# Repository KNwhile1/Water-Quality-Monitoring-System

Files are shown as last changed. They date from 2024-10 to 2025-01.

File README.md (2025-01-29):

# Project-PPS

# Water Quality Measurement Device for Lakes or Rivers with Geolocation, Connected to the Internet (Cloud)

## Context and Origin
Our company specializes in manufacturing devices to measure water quality in lakes and rivers. Traditionally, our teams travel by boat to take measurements on-site and collect water samples for laboratory analysis. Each measurement includes data on the date, time, temperature, geographical location, and water sample, all recorded on paper. One employee had the innovative idea of creating a device that would automatically take measurements and record data without the need for paper notes or water samples. This device would allow real-time water quality measurements and instantly send the data to our databases to be visualized on a Google Maps map, offering up-to-date accessibility for everyone.

In order to bring this vision to life and continue our commitment to environmental health, we have decided to develop and commercialize this product, which will replace our current methods.

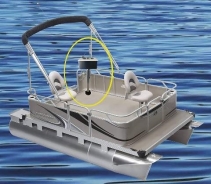
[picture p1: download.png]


## General Need
The required device is a water quality measurement system capable of collecting and transmitting data on the concentration of certain gases (such as oxygen) and water temperature. It must include geolocation, battery level, and send the data to a cloud platform via the LoRaWAN network. The data should be displayed on a Google Maps map.

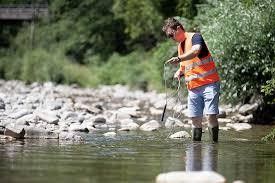
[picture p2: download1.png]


## Objectives
- Design a device capable of measuring water quality
- Transmit the collected data to a cloud platform accessible by employees
- Display water quality data on a Google Maps map in real-time
- Key Functions

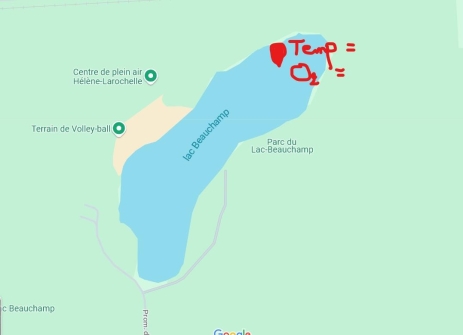
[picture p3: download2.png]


## The device can
- Measure oxygen (O2) concentration in the water
- Measure water temperature
- Provide geolocation data (latitude and longitude), as well as the date and time of the measurement
- Indicate voltage and battery level
- Send the collected data via the LoRaWAN network to a cloud platform (ThingsBoard)
- Update data every 5 minutes
- Display the collected data on an integrated Google Maps map on the ThingsBoard platform

## Required Components (images)
- Maduino Zero LoRaWAN
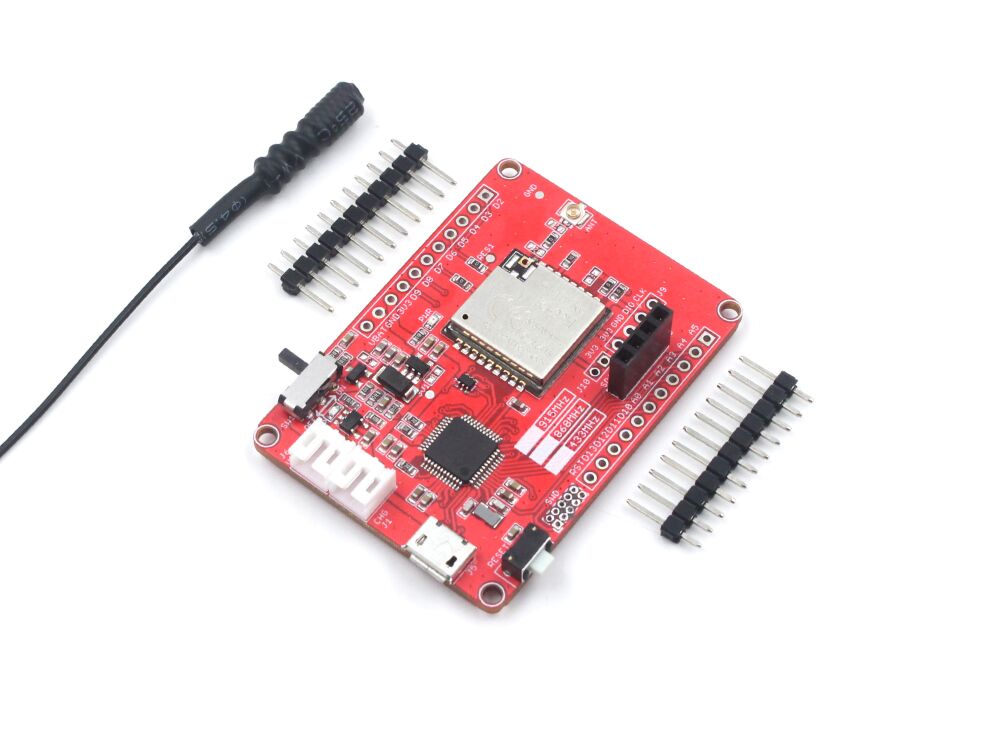
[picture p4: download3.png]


- Waterproof 1-WIRE temperature sensor (5V)
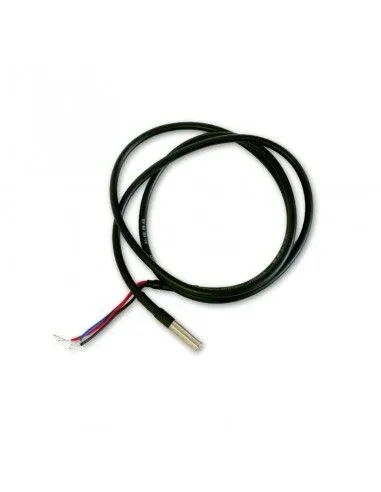
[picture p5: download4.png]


- Waterproof oxygen concentration sensor (5V)
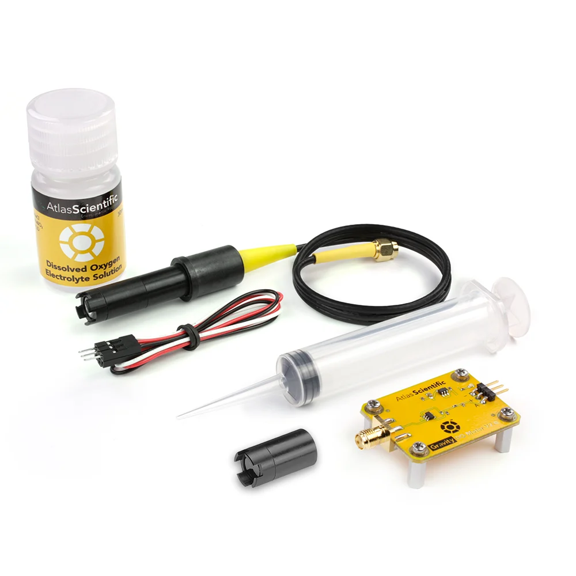
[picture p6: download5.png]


- 1K Ohm 1206 resistor
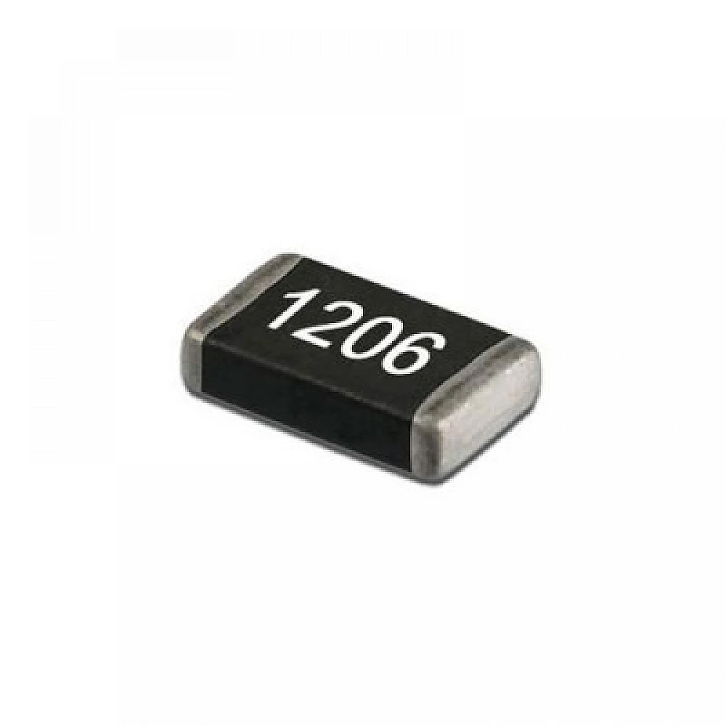
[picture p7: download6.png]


- 2 AA 1.5V batteries
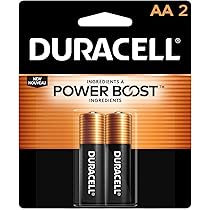
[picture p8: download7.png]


- Battery holder for 2 AA batteries
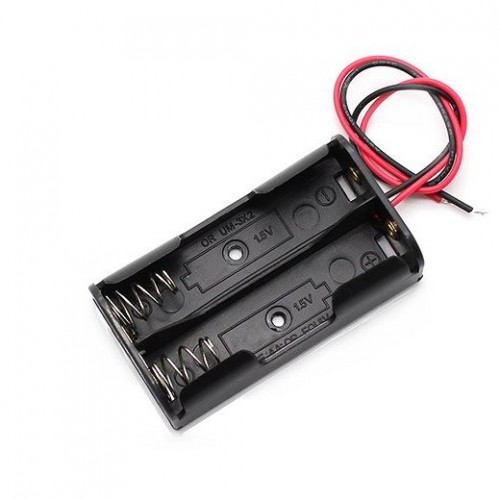
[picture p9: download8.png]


- On/Off switch to control power
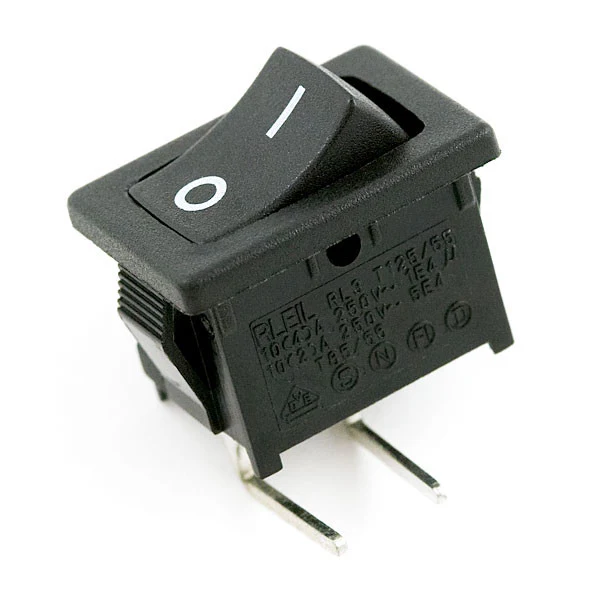
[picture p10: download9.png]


- 3.3V to 5V boost converter
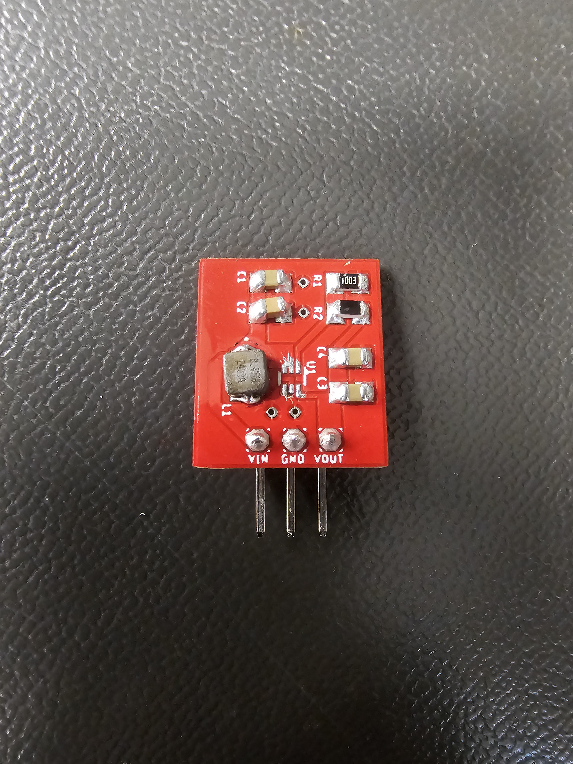
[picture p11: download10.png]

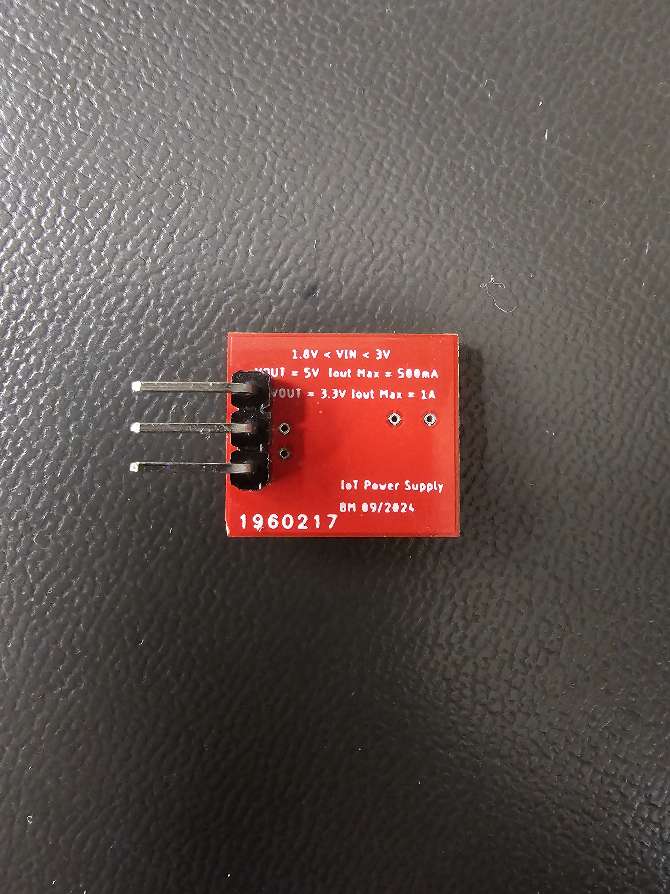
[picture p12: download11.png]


*See the **Project Purchase Links** category for purchase links*

## Conclusion
This project aims to revolutionize how we measure and track the water quality of lakes and rivers. With this device, we will be able to provide precise, instant, and accessible data to our entire team while ensuring improved environmental monitoring.

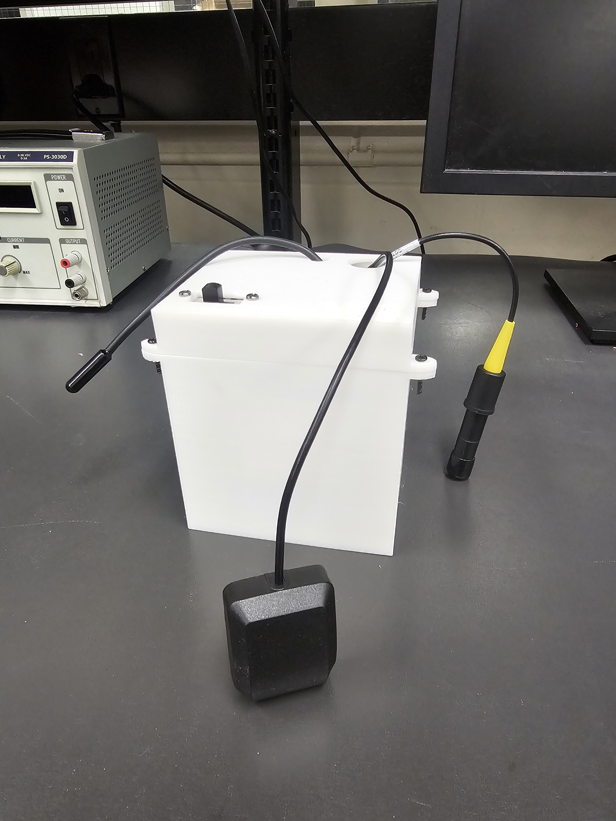
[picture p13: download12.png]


*Representation of the project assembly*

# Functional File Versions for this Project
- /Codes/CodeV1.3 ---> **CodeV1.3.ino**
- /3D_Prints/Boiter3DV1.1 ---> **PPS_Boitier.stl** and **PPS_CouvercleBoitier.stl**
- /Schematics/CircuitV1.3 ---> **PPS_schematic.sch**
- /Schematics/MatrixV1.3 ---> **PPS_schematic.brd**

# Problems Encountered
See /Problem_List ---> Liste_problemes_PPS.xlsx

# Project Purchase Links
See /Component_List ---> Liste_composants_PPS.xlsx

# Additional Information Links
- [CayenneLPP](https://github.com/myDevicesIoT/CayenneLPP)
- [Arduino LoRaWAN Device Library](https://github.com/TheThingsNetwork/arduino-device-lib)
- [ASR650X AT Command Introduction](https://www.hoperf.com/data/upload/back/20190605/ASR650X%20AT%20Command%20Introduction-20190605.pdf)
- [Maduino Zero LoRaWAN](https://github.com/Makerfabs/Maduino-Zero-Lorawan/tree/Ra07)
- [Github chirpstack docker](https://github.com/chirpstack/chirpstack-docker)
- [ChirpStack Documentation](https://www.chirpstack.io/docs/)
- [ThingsBoard Documentation](https://thingsboard.io/)

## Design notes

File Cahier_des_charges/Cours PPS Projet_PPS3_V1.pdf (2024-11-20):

Cours PPS_Projet PPS3_V1 | Copyleft B. Manai

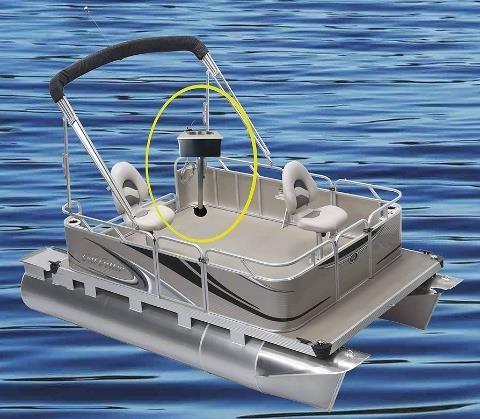
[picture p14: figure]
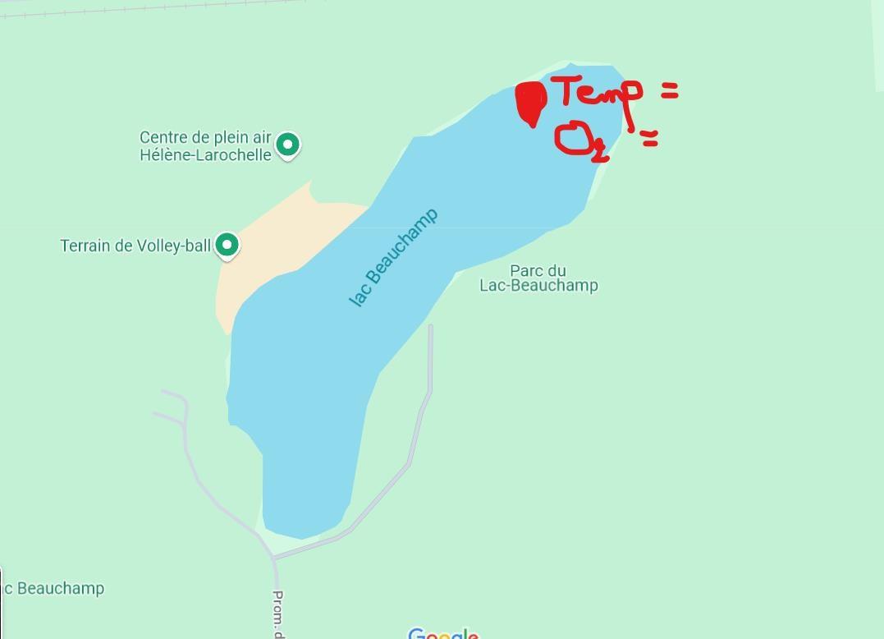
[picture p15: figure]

2024-10-03

## Cours Préparation au Projet et au Stage (PPS)

## Projet : Dispositif de mesure de la qualité de l'eau d'un lac ou d'une rivière avec géolocalisation connecté à internet (Cloud)

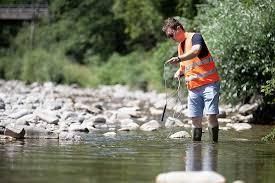
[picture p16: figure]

A. Contexte et origine
Notre compagnie fabrique des dispositifs de mesure de la qualité de l'eau des lacs et des rivières. Habituellement nos équipes se déplace sur un bateau/barque pour faire des mesures sur place et recueillir des échantillons afin de les analyser au laboratoire. Chaque mesure correspond à une date, une heure, une température, une position géographique et un échantillon d'eau. L'ensemble est consigné dans un support papier et l'échantillon dans un contenant pour l'analyse au laboratoire. Une idée novatrice nous a été proposé par un de nos employés qui a imaginé un dispositif qui permettrait de faire les mesures et relèvement en une seule fois sans devoir prendre des notes sur papiers ni d'échantillons. Ainsi la qualité de l’eau est mesurée au moment de la sortie et les données sont envoyées instantanément à nos bases de données et reportées directement sur une carte de type Google Maps de sorte que toutes les personnes puissent connaitre la qualité de l’eau à chaque instant. Comme nous avons le souci de la santé environnementale nous avons donc décidé de réaliser ce produit qui sera vendu et remplacera les produits existants
Nous avons pensé donc à la réalisation d’un dispositif de 1ème génération permettant l’envoi des mesures de la concentration de O2 et de la température de l'eau via le réseau LoRaWAN directement sur une plateforme infonuagique (Cloud) et les afficher sur Google Maps.
B. Besoin général

Le besoin est un dispositif de mesure de la qualité de l’eau. La mesure de la qualité de l’eau se faitsur la base de mesures de concentration dansl’eau de certains gaz comme l'oxygène O2. Les fonctions principales sont la mesure des concentrations, la géolocalisation, la tension de la batterie et l’envoi des données via LoRaWAN sur une plateforme connectée à internet et l’affichage des données sur une carte Google Maps.

C. Objectifs
L’objectif ici est de concevoir et réaliser un dispositif qui serait capable de mesurer la qualité de l’eau et l’afficher sur une carte de type Google Maps à l’endroit et à l’heure où les données ont été requises ainsi que l’envoie de ces données sur une plateforme cloud accessible aux employés.
D. Fonctions principales
- La solution doit pouvoir mesurer la concentration d’oxygène (O2) dans l’eau.
- La solution doit pouvoir mesurer la concentration d’azote () dans l’eau.
- La solution doit pouvoir mesurer la température de l’eau.
- La solution doit pouvoir fournir les données géographiques de l’endroit où l’échantillon a été recueilli ainsi que la date et l’heure.
- La solution doit pouvoir être alimentée par du 5V.
- La solution doit pouvoir renseigner sur l’état de la batterie.

- La solution doit pouvoir envoyer les données (concentration des gaz, Température de l’eau, tension de la batterie, niveau de la batterie) via LoRaWan sur une la platform Cloud ThingsBoard.
- La solution doit pouvoir mettre à jour les données toutes les 5 minutes.
- Les données de solution doivent pouvoir être accessibles par les bases de données de l'entreprise.
- La solution doit pouvoir afficher les données sur les concentrations de gaz, sur la température de l’eau et le niveau de batterie sur une carte de type Google Maps.
- La solution doit pouvoir afficher la carte Google Maps sur la plateforme ThingsBoard.
E. Contraintes
a. Alimentation

2 piles AA de 1.5V chacune

1 support pour 2 piles AA

1 interrupteur Marche/Arrêt

b. Capteurs

Temperature, O2

c. MCU / Module WiFi
Maduino LoRaWAN d. Support de la partie électronique

Carte de montage électronique et produit fini sur PCB simple ou double face. Les MCUs ne doivent pas être soudés sur la carte. Prévoir des supports pour cette fin.

e. Boitier 3D

Une simple boite parallélépipédique suffit largement. Doit comporter un accès au port USB de programmation du MCU. Les interrupteurs doivent être accessible depuis l’extérieur du boitier. Un accès des capteurs à l’extérieur du boitier doit être assuré. Pour des raisons de sécurité aucune colle ne sera permise pour coller le PCB au boitier. Prévoir 4 trous aux 4 coins du PCB pour une fixation au boitier avec des vis M2.

f. Cloud

Doit afficher sur une carte Google Maps les valeurs en temps réel de la température, les concentrations de gaz, la tension de la batterie et signaler un niveau de batterie faible, lorsque la tension de la batterie devient inférieure à 2x1V.

Doit utiliser la plateforme ThingsBoard. Doit afficher la concentration en O2 et la température de l'eau sur une période d’une journée avec mise à jour toutesles 5 minutes. Affichage de la valeur actuelle. Doit afficher la tension de la batterie et signaler un niveau de batterie faible lorsque la tension de la batterie devient inférieure à 2x1V. Doit reporter sur une carte Google Maps les dernières valeurs mesurées de la concentration en O2, la température de l'eau et du niveau de la batterie.

g. Plateforme de développement
Fusion 360
h. Plateforme de documentation
La gestion du projet doit être entièrement réalisé sur GitHub
F. Acteurs
Les | différents | acteurs | liés | à | ce | projet | sont | les | suivants | :
Concepteurs/conceptrices | :
- | Camille | Courtemanche, | en | charge | du | PCB
- | Andyl | Omontola | Ouabi, | en | charge | de | l’alimentation
- | Kirstan | Niamba, | en | charge | du | cloud
- | Esther | Priscilla | Zoukou, | en | charge | du | boiter
Autres | | | | | | | | | | :
-M. | Bilal | Manaï, | client
-M. Bilal Manaï, superviseur du projet et enseignant au département TGÉ du Cégep de l’Outaouais
-M. Maxime Gillespie, technicien du département TGÉ du Cégep de l’Outaouai
-M. Alexis Maisonneuve, technicien du département TGÉ du Cégep de l’Outaouais

G. Livrables
- | | Cartes | | | électroniques
- | Bureau | d’affichage | des | données | (Thingsboard)
- | | Produit | | | assemblé
- | | | Produit | | installé
- | | Accès | | aux | données
H. Échéancier
14 | | | novembre | | 2024
I. Budget
Maximum de 100 dollars canadien

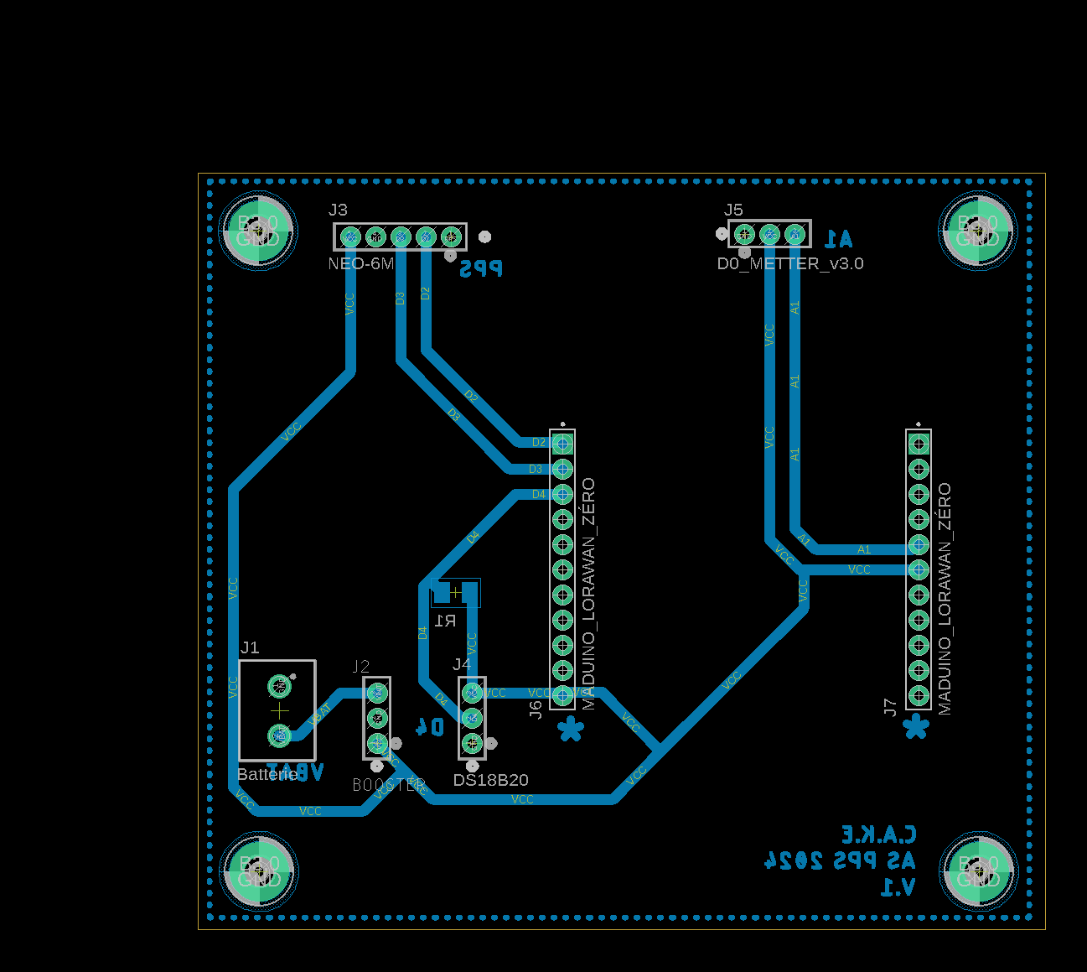
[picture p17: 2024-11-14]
Schématiques/MatricielV1.3/PPS_schematic.png

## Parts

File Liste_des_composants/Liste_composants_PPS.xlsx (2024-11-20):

Liste des pieces
Élève : Camille Courtemanche |  |  | Tuteur: Bilal Manaï
Projet : PPS |  |  |  |  |  |  | Prix/composant (hors taxes) |  | Total | Page web (URL | Fiche technique | Image | Remarque du client | Remarques du technicien
Quantité | numéro de pièce (SKU) | Fabricant | Fournisseur | Fourni par | Disponible (magasin) | Description | USD | CAD | $710.68
2 | PPTC031LFBN-RC | Sullins Connector Solutions | Digikey | Département (magasins) | oui | 3 Positions Embase Connecteur 0,100 po (2,54mm) Trou traversant Étain (Connecteur Femelle) | $0.65 | $0.91 | $1.82 | https://www.digikey.ca/fr/products/detail/sullins-connector-solutions/PPTC031LFBN-RC/810143 | https://mm.digikey.com/Volume0/opasdata/d220001/medias/docus/937/Female_Headers.100_DS.pdf |  |  | Contient 3 Pins (femelle)
2 | M20-7821146 | Harwin Inc. | Digikey | Département (magasins) | oui | 12 Positions Embase Connecteur 0,100 po (2,54mm) Trou traversant Étain | $2.56 | $3.58 | $7.17 | https://www.digikey.ca/fr/products/detail/harwin-inc/M20-7821146/3919446 | https://cdn.harwin.com/pdfs/M20-782.pdf |  |  | Contient 11 Pins (femelle)
1 | RC1206FR-074K7L | YAGEO | Digikey | Département (magasins) | oui | 4.7 kOhms ±1% 0,25W, 1/4W Pavé résistif 1206 (3216 métrique) Résistant à l’humidité Couche épaisse | $0.16 | $0.22 | $0.22 | https://www.digikey.ca/fr/products/detail/yageo/RC1206FR-074K7L/728887 | https://www.yageo.com/upload/media/product/products/datasheet/rchip/PYu-RC_Group_51_RoHS_L_12.pdf
1 | 08055C102KAT2A | Würth Elektronik | Digikey | Département (magasins) | oui | 2 Borniers - Fil à carte Horizontal avec carte 0,197po (5,00mm) Trou traversant | $0.58 | $0.81 | $0.81 | https://www.digikey.ca/fr/products/detail/w%C3%BCrth-elektronik/691137710002/6644051 | https://www.we-online.com/components/products/datasheet/691137710002.pdf
1 | PPTC051LFBN-RC | Sullins Connector Solutions | Digikey | Département (magasins) | oui | 5 Positions Embase Connecteur 0,100 po (2,54mm) Trou traversant Étain | $0.84 | $1.18 | $1.18 | https://www.digikey.ca/fr/products/detail/sullins-connector-solutions/PPTC051LFBN-RC/807239 | 5 Positions Embase Connecteur 0,100 po (2,54mm) Trou traversant Étain
1 | RG191 | Ezurio LLC | Digikey | Département (magasins) | oui | GATEWAY WIFI LORA ETHERNET US | $265.00 | $371.00 | $371.00 | https://www.digikey.ca/en/products/detail/ezurio-llc/RG191/7356131?gad_source=1 | https://connectivity-staging.s3.us-east-2.amazonaws.com/2020-03/CS-PB-RG1xx-GATEWAY_v1_5.pdf
1 | RB-Mkf-36 | OPHMALORA | RobotShop | Département (magasins) | oui | LPWAN ASSET TRACKER KIT AMAZON | A/N | $33.52 | $33.52 | https://ca.robotshop.com/products/maduino-zero-lorawan-915mhz?gad_source=1 | https://wiki.seeedstudio.com/Wio-Tracker_Introduction/
1 | MOD-120 Neo-6M UBLOX GPS Module | ABRA | ABRA | Département (magasins) | oui | GPS module with antenna, adapter, battery. Extra : clock pulse output pin | A/N | $32.62 | $32.62 | https://abra-electronics.com/wireless/gps/modules/mod-120-neo-6m-ublox-gps-module.html | https://content.u-blox.com/sites/default/files/products/documents/NEO-6_DataSheet_%28GPS.G6-HW-09005%29.pdf
1 | SEN-11050 | SparkFun Electronics | Digikey | Département (magasins) | oui | TEMP SENSOR WTRPRF DS18B20 11050 | $11.25 | $15.75 | $15.75 | https://www.digikey.ca/en/products/detail/sparkfun-electronics/SEN-11050/5721423?gad_source=1 | https://mm.digikey.com/Volume0/opasdata/d220001/medias/docus/1818/SEN-11050_Web.pdf
1 | RB-Atl-54 | Kit-105DX | RobotShop | Département (magasins) | oui |  | A/N | $246.41 | $246.41 | https://ca.robotshop.com/products/gravity-analog-dissolved-oxygen-kit?gad_source=1 | https://cdn.robotshop.com/media/a/atl/rb-atl-73/pdf/gravity-analog-dissolved-oxygen-meter-datasheet.pdf
1 | 61300311121 | Würth Elektronik | Digikey | Département (magasins) | oui | CONN HEADER VERT 3POS 2.54MM | $0.13 | $0.18 | $0.18 | https://www.digikey.ca/en/products/detail/w%C3%BCrth-elektronik/61300311121/4846825?productid=4846825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 | https://www.we-online.com/components/products/datasheet/61300311121.pdf

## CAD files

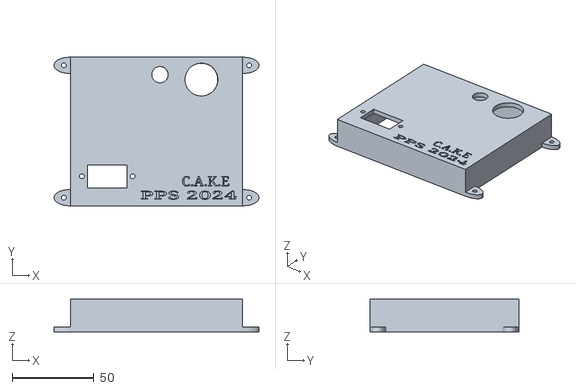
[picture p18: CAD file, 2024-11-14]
Impressions3D/Boiter3DV1/PPS_CouvercleBoitier.stl
125.0 x 90.7 x 20.0

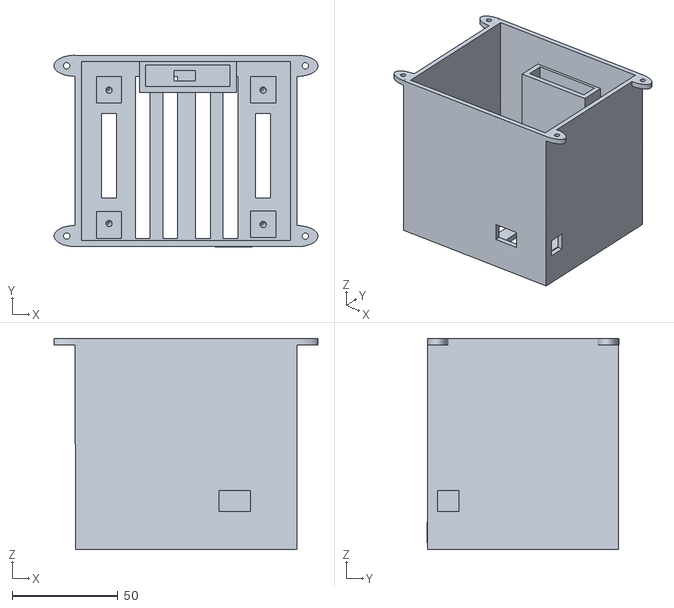
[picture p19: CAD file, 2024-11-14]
Impressions3D/Boiter3DV1/PPS_Boitier.stl
125.1 x 90.8 x 100.0

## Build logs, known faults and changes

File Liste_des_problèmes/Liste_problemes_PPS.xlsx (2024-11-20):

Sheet: Feuille 1
Dans cette colomne préciser le nom de votre équipe | Dans cette colomne préciser le titre de votre projet PPSx | Dans cette colomne compléter les Prénoms, Noms de l'équipe |  |  | Dans cette colomne décrire au moins 3 problèmes rencontrés pour chaque composante (matérielle, logicielle, réseau et cloud) | Dans cette colomne décrire les solutions envisagées en vis à vis de chaque problème | Dans cette colomne préciser quelle solution a été choisie | Dans cette colomne préciser pour quelles raisons la solution a été choisie
Projet | Équipe | Membres de l'équipe | Composante | Problème | Description du problème | Solutions | Choix | Argumentation
 |  |  | Matérielle (au sens électronique : PCB, plaque à essai, ...) | 1 |  | 1:
 |  |  |  |  |  | 2:
 |  |  |  |  |  | 3 :
 |  |  |  | 2 |  | 1:
 |  |  |  |  |  | 2:
 |  |  |  | 3 |  | 3:
 |  |  |  | 4 |  | 1:
 |  |  |  |  |  | 2:
 |  |  |  |  |  | 3:
 |  |  | Logicielle (embarqué) | 1 |  | 1:
 |  |  |  |  |  | 2:
 |  |  |  |  |  | 3 :
 |  |  |  | 2 |  | 1:
 |  |  |  |  |  | 2:
 |  |  |  | 3 |  | 1:
 |  |  |  |  |  | 2 :
 |  |  |  |  |  | 3 :
 |  |  | Réseau (WiFi / LoRaWAN) | 1 |  | 1 :
 |  |  |  |  |  | 2 :
 |  |  |  |  |  | 3 :
 |  |  |  | 2 |  | 1 :
 |  |  |  |  |  | 2 :
 |  |  |  | 3 |  | 1 :
 |  |  |  |  |  | 2 :
 |  |  |  |  |  | 3:
 |  |  | Cloud (ThingsBoard) | 1 |  | 1:
 |  |  |  |  |  | 2 :
 |  |  |  |  |  | 3 :
 |  |  |  | 2 |  | 1 :
 |  |  |  |  |  | 2 :
 |  |  |  | 3 |  | 1 :
 |  |  |  |  |  | 2 :
 |  |  |  |  |  | 3 :
 |  |  | Boitier (3D) | 1 |  | 1:
 |  |  |  |  |  | 2 :
 |  |  |  |  |  | 3 :
 |  |  |  | 2 |  | 1 :
 |  |  |  |  |  | 2 :
 |  |  |  | 3 |  | 1 :
 |  |  |  |  |  | 2 :
 |  |  |  |  |  | 3:

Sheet: BlueScreen
Dans cette colomne préciser le titre de votre projet PPSx | Dans cette colomne préciser le nom de votre équipe | Dans cette colomne compléter les Prénoms, Noms de l'équipe |  |  | Dans cette colomne décrire au moins 3 problèmes rencontrés pour chaque composante (matérielle, logicielle, réseau et cloud) | Dans cette colomne décrire les solutions envisagées en vis à vis de chaque problème | Dans cette colomne préciser quelle solution a été choisie | Dans cette colomne préciser pour quelles raisons la solution a été choisie
Projet | Équipe | Membres de l'équipe | Composante | Problème | Description du problème | Solutions | Choix | Argumentation
Projet PPS2 : | Équipe BlueScreen | David Landry, Jérémie Cadieux, Tristan Comtois et Damien Tweedy | Matérielle (au sens électronique : PCB, plaque à essai, ...) | 1 | La première version de notre PCB a été mal conçue et n'avait pas pris en considération que pour les composantes traversantes c'est sur la couche bottom que nous devions souder. Cela a eu comme incidence qu'une fois assemblé, notre Maduino était à l'envers. | 1: Essayer de souder les collecteurs en surface | Choix 2 | Problème 1 : Nous avons choisit de repenser et refaire la matricielle car il y avait beaucoup de problème de conception majeur avec notre première version imprimer de notre PCB. De plus nous en avons profiter pour réduire considérablement la dimension du PCB pour permettre le montage sur un casque de vélo plus réaliste. Problème 2 : Nous avons choisit de faire un seul BOOST de 5V pour alimenté le Maduino avec son entré VBAT car celui-ci à un option intégré de fournir de 3V3 que nous pouvons utilisé pour alimenté notre capteur GPS. Cette options est plus compacte et consomme moins d'énergie électriquement que les choix 1 et 2. Problème 3 : Nous avons choisit de vérifier les soudures et de faire des tests électriques. Nous avons trouvé un problème important. VIN et le GROUND étaient connectés ensemble à l'intérieur du bornier male. Le plastique avait fondu et connecté les deux signaux électriquement. Nous avons dessoudé et resoudé un autre connecteur. Le VOUT est maintenant 2.4V, on suspecte qu'il y a un problème avec la composante tps61023dlr.
 |  |  |  |  |  | 2:Repenser et refaire la matricielle en prenant en considération l'orientation et la couche de soudure.
 |  |  |  |  |  | 3 :
 |  |  |  | 2 | Choix des sources d’alimentation 5V et 3V3, Nous avons changé d’idée à plusieurs reprises lors de la considération des sources d’alimentation 5V et 3V3. | 1:Faire un boost de 5V et utilisé un régulateur de tension 3.3V. Cette solution c’est avéré être mauvaise car elle utilisait des composantes qui consommait trop de courant par rapport à d’autre options possibles. | Choix 3
 |  |  |  |  |  | 2:Utilisé 2 boosts (3,3V et 5V) pour alimenter nos composantes. Nous avons vite rejeté cette option lorsque nous avons consulté en profondeur la datasheet et les schématiques du Maduino Zero pour réaliser qu’en utilisant une alimentation par batterie, le Maduino devait être alimenté par du 5V et à la possibilité intégrée de fournir de 3,3V.
 |  |  |  |  |  | 3: Faire un seul boost de 5V pour alimenter le Maduino via le connecteur VBAT et utilisé l’interrupteur SW1 pour choisir l’alimentation USB ou via la Batterie. On utilise le 3,3V fournis par le Maduino pour alimenter le module GPS et le boost de 5V pour alimenter le capteur de gaz.
 |  |  |  | 3 | Problème avec le Boost 5V, une fois le circuit soudé, il ne fournissait pas 5V en sortie. Nous avons mis 3V en entré avec 30mA et mesuré VOUT et VOUT. VIN = 2.98V et VOUT = 0 | 1: Vérifier les soudures et refaire celle qui sembre être flottante | Choix 2 et 3
 |  |  |  |  |  | 2: Test de continuité en mode résistance avec notre multimètre
 |  |  |  |  |  | 3: Refaire le circuit avec de nouvelles composantes
 |  |  |  | 1 | Problème avec l’utilisation du GPS avec communication UART (RX et TX). | 1: Utiliser les bibliothèques tel que SoftwareSerial ou AltSoftSerial pour réassigné les pins RX et TX | Choix 2
 |  |  | Logicielle (embarqué) |  |  | 2: Utiliser les pin D2 et D3 en l'assignation sercom2 . |  | Problème 1 : Nous avons choisit d'utiliser les pins D2 et D3 pour faire la communications UART RX et TX car nous avons vu plusieurs autre projet en ligne qui utilisait c'est 2 pins avec d'autre capteurs avec le même Maduino. Les librairies du choix 1 n'est pas compatible avec notre microcontroleurs. Le choix 3 requière l'ajoût d'une autre composante qui prend de la place, consomme de l'électricité et nous n'étions pas certain que sa serait fonctionnelle. Nous avons donc décidé de ne pas choisir cette solution. Problème 2 : Nous avons essayé d'utilisé des lingetttes alcoolisé et d'autre librairie, mais nous n'avons pas été capable de capté des données pertinante avec le capteur de gaz.
 |  |  |  |  |  | 3 : Utiliser un convertisseur CP2104 USB à Seriel
 |  |  |  | 2 | Problème avec l'utilisation du capteur de gaz, nous étions limité avec les tests de fonctionalités. Nous recevions des valeurs PPM qui n'était pas possible | 1 : Utilisé le capteur de gaz pour détecté l'alcool et utilisé des serviettes nettoyante alcolisé. | Choix 1 et 3
 |  |  |  |  |  | 2 : Essayer d'autre librairies avec notre capteur de gaz
 |  |  |  |  |  | 3 : Essayer un autre capteur de gaz pour vérifier si le notre avait des défectuosités
 |  |  |  | 3 |  | 1 :
 |  |  |  |  |  | 2: | Choix
 |  |  |  |  |  | 3 :
 |  |  |  | 1 | Difficulté à se familiariser avec LoRaWan et Chirpstack | 1 : Lire des blogs et regarder des videos sur le sujet | Choix 1 et 2
 |  |  | Réseau (WiFi / LoRaWAN) |  |  | 2 : Écouter la démonstration de maxime |  | Problème 1 : Travailler avec ChirpStack et LoRaWAN était accablant au début, car c'était un domaine nouveau pour nous. Nous avons donc commencé par lire et nous informer sur le sujet avant de nous lancer dans cette partie du projet. Problème 2 : Après avoir connecté le Maduino Zero à ChirpStack via LoRaWAN, nous avons réussi à recevoir les données, mais nous n'avons pas réussi à les envoyer vers ThingsBoard.
 |  |  |  |  |  | 3 :
 |  |  |  | 2 | Problème lorsque des informations sont envoyer via Chirpstack | 1 : Relire le tutoriel de Maxime sur LoRaWAn | Choix 1 et 2
 |  |  |  |  |  | 2 : Créer une nouvelle application, avec une nouvelle clé
 |  |  |  | 3 |  | 1 :
 |  |  |  |  |  | 2 : | Choix
 |  |  |  |  |  | 3:
 |  |  |  | 1 | Difficulté à se familiarriser avec ThingsBoard et le Dashboard ( widgets, google map) | 1 : Regarder des tutoriels | Choix 1
 |  |  | Cloud (ThingsBoard) |  |  | 2 : Essayer les differents widgets dans des examples |  | Problème 1 : De manière similaire à ChirpStack et LoRaWAN, nous avons dû nous familiariser avec ThingsBoard et les différents widgets du tableau de bord. Nous avons regardé des tutoriels et, finalement, nous avons réussi à créer un tableau de bord adéquat pour notre projet. Problème 2 : Lors des tests de la capacité de ThingsBoard à recevoir des données, nous pouvions envoyer des valeurs fixes via le terminal Windows, mais nous n'avons pas réussi à recevoir les valeurs de notre capteur de gaz ou du GPS via le Maduino Zero.
 |  |  |  |  |  | 3 :
 |  |  |  | 2 | Difficulté recevoir les informations de Chirpstack sur ThingsBoard | 1 : Lire la documentation que maxime a créer sur tge.info | Choix 1
 |  |  |  |  |  | 2 : Changer la configuration de Chirpstack et ThingsBoard
 |  |  |  | 3 |  | 1 :
 |  |  |  |  |  | 2 : | Choix
 |  |  |  |  |  | 3 :
 |  |  |  | 1 | Problème avec les dimensions de la première version du boîtier, les murs étaient trop épaisses et celui-ci était trop gros pour porter sur un casque. | 1: Refaire le boîtier au complet pour que celui-ci respecte les normes d'épaisseur, de compactibilité et de grandeur. | Choix 1 et 2
 |  |  | Boitier (3D) |  |  | 2 : Raptisser les parois du boîtier pour qu'il puisse être plus compact et qu'il puisse s'installer sur un casque de vélo. |  | Problème 1 : Le problème de la première version du boîtier était que les parois étaient trop épaisses, ce qui empêchait son installation adéquate sur un casque de vélo. En refaisant le boîtier, nous avons pu réduire l'épaisseur des parois pour qu'il soit plus compact et qu'il puisse s'installer correctement sur le casque de vélo. Problème 2 : Les dimensions de la deuxième version du boîtier sont encore inexactes. Les parois sont trop minces pour permettre l'insertion des vis nécessaires à la fermeture du boîtier, et la fente n'autorise pas un accès facile au Maduino. En refaisant le boîtier avec des parois un peu plus épaisses et en agrandissant l'ouverture pour faciliter l'accès au Maduino, nous obtiendrons un boîtier conforme à nos exigences. Problème 3 : Les dimensions des trous pour le capteur d'air et l'interrupteur sont trop petites, ce qui empêche leur insertion précise dans le boîtier. En limant les trous, nous avons pu corriger les légères erreurs d'impression en les agrandissant.
 |  |  |  |  |  | 3 : Ajuster les trous et les parois à la lime pour qu'il soit à la bonne épaisseur et grandeur.
 |  |  |  | 2 | Deuxième version : dimension des troues d'attachement pour le couvercle et la fente à l'avant est trop petite pour permettre l'accès du Maduino de l'extérieur | 1 : Refaire le boîtier pour aggrendir les parois pour pouvoir insérer des vis et avoir un accès plus facile du Maduino de l'extérieur.
 |  |  |  |  |  | 2 : Ajuster les trous à la lime pour y insérer les vis et le composant. | Choix 1
 |  |  |  |  |  | 3 : Percer les trous pour y insérer les vis.
 |  |  |  | 3 | Dimension des troues pour le capteur et la switch n'étaient pas parfaitement la bonne dimmension. | 1 : Refaire le boîtier pour aggrendir les trous pour pouvoir insérer le capteur et la switch sans avoir besoin de limer les extrémiter.
 |  |  |  |  |  | 2 : Ajuster les trous à la lime pour y insérer les composants. | Choix 2
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

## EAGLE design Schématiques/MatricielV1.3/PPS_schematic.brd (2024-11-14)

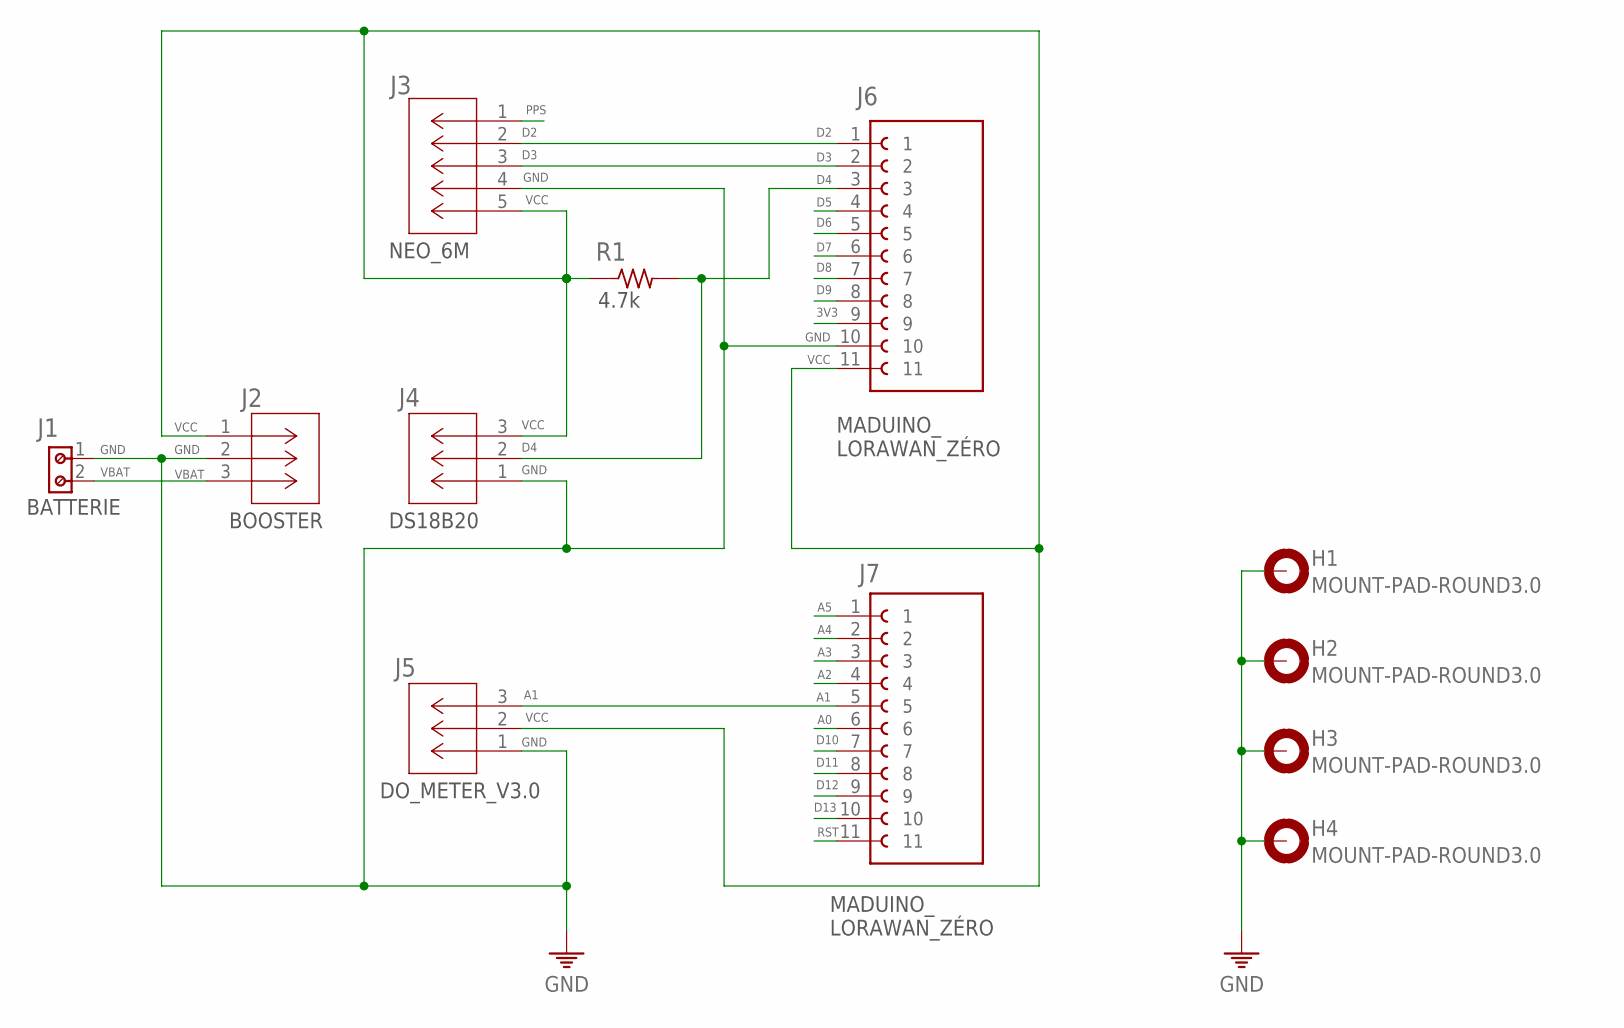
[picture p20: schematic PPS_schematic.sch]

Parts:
H1, H2, H3, H4: MOUNT-PAD-ROUND3.0; 3,0-PAD
J1: Batterie; 691137710002
J2: BOOSTER; CON3_1X3_TU_HTS_SAI
J3: NEO-6M; CONN5_1LFBN-RC_SUL
J4: DS18B20; CONN_PPTC031_SUL
J5: D0_METTER_v3.0; CONN_PPTC031_SUL
J6, J7: MADUINO_LORAWAN_ZÉRO; HARWIN_M20-7821146
R1: 4.7k; M1206

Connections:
3V3: J6.9
A1: J5.3, J7.5
A2: J7.4
A3: J7.3
A4: J7.2
A5: J7.1
D2: J3.2, J6.1
D3: J3.3, J6.2
D4: J4.2, J6.3, R1.2
D5: J6.4
D6: J6.5
D7: J6.6
D8: J6.7
D9: J6.8
D10: J7.7
D11: J7.8
D12: J7.9
D13: J7.10
GND: H1.B3,0, H2.B3,0, H3.B3,0, H4.B3,0, J1.1, J2.2, J3.4, J4.1, J5.1, J6.10
PPS: J3.1
RST: J7.11
VBAT: J1.2, J2.3

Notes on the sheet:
BOOSTER
DS18B20
DO_METER_V3.0
NEO_6M
BATTERIE
MADUINO_ LORAWAN_ZÉRO

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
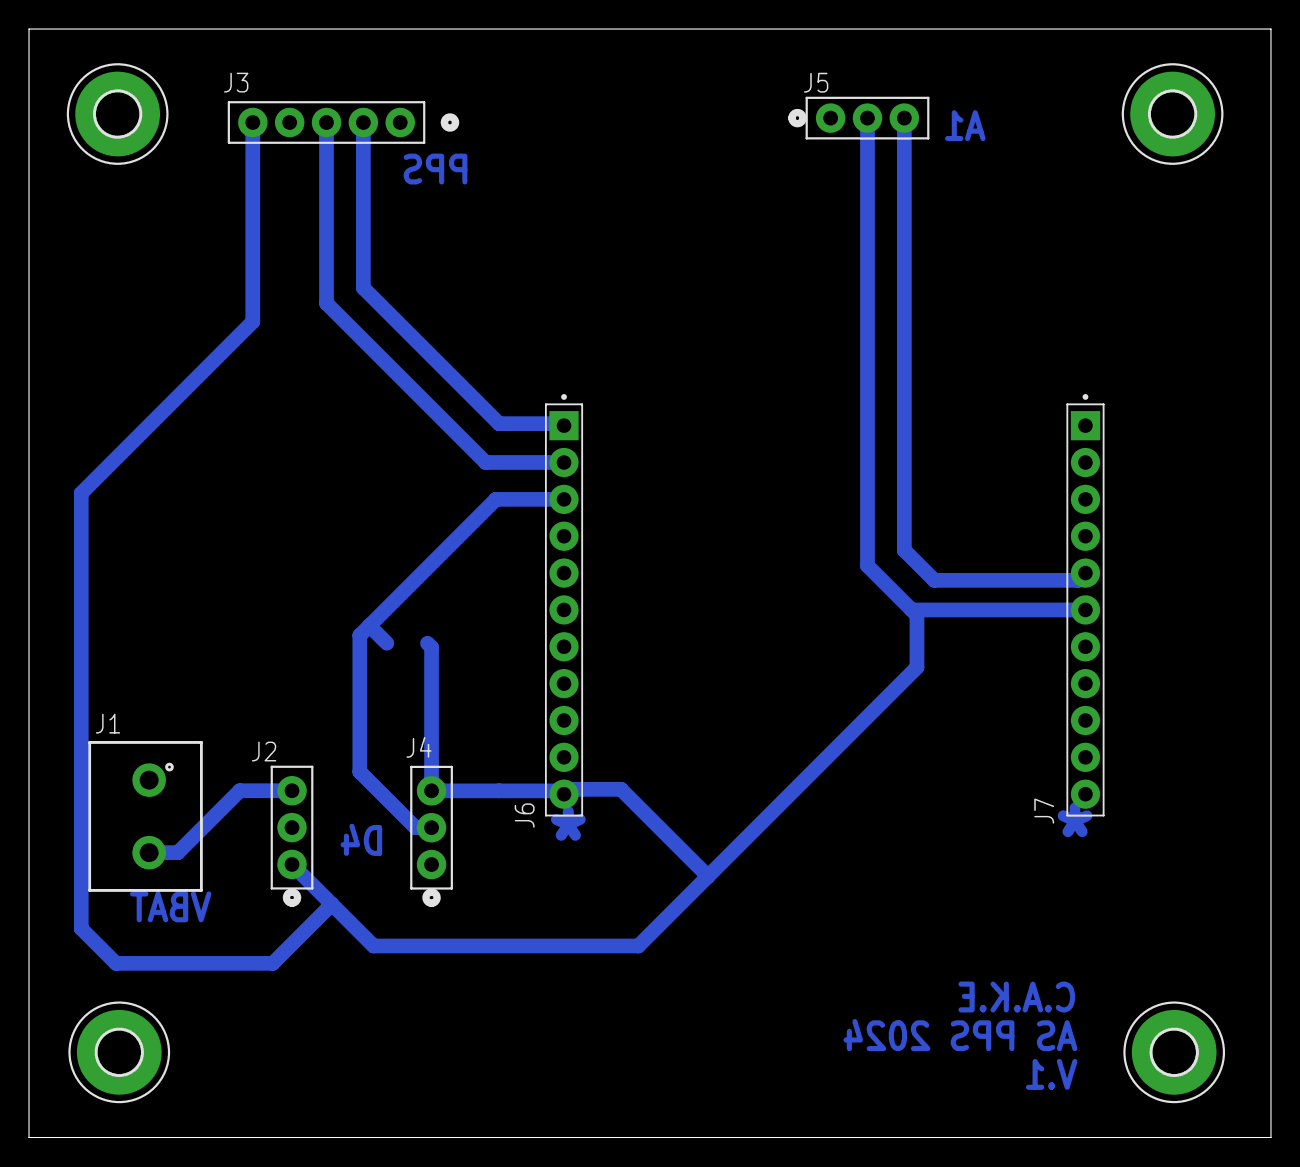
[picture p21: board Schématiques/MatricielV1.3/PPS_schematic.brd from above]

Board: 2 copper layers, 85.6 x 76.4 mm, 12 parts (1 on the bottom side), 7 nets.

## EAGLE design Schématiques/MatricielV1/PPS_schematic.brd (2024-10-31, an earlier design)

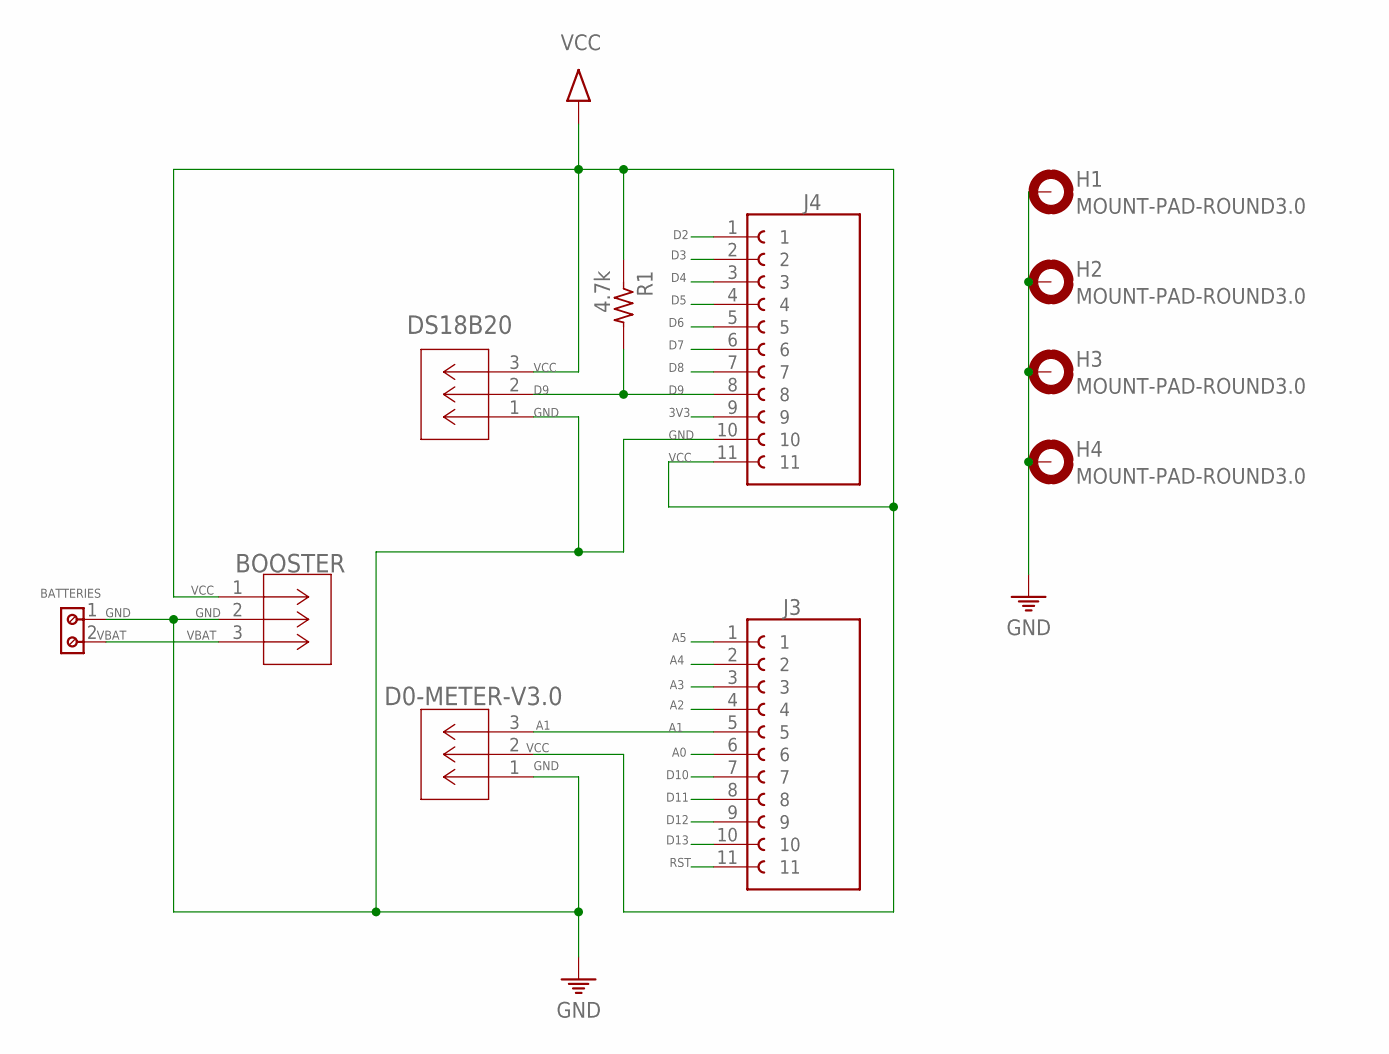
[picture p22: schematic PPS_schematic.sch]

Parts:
BATTERIES: 691137710002
BOOSTER: TS-103-T-ACON3_1X3_TU_HTS_SAI; CON3_1X3_TU_HTS_SAI
D0-METER-V3.0: PPTC031LFBN-RCCONN_PPTC031_SUL; CONN_PPTC031_SUL
DS18B20: PPTC031LFBN-RCCONN_PPTC031_SUL; CONN_PPTC031_SUL
H1, H2, H3, H4: MOUNT-PAD-ROUND3.0; 3,0-PAD
J3, J4: M20-7821146; HARWIN_M20-7821146
R1: 4.7k; M1206

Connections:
3V3: J4.9
A0: J3.6
A1: D0-METER-V3.0.3, J3.5
A2: J3.4
A3: J3.3
A4: J3.2
A5: J3.1
D2: J4.1
D3: J4.2
D4: J4.3
D5: J4.4
D6: J4.5
D7: J4.6
D8: J4.7
D9: DS18B20.2, J4.8, R1.2
D10: J3.7
D11: J3.8
D12: J3.9
D13: J3.10
GND: BATTERIES.1, BOOSTER.2, D0-METER-V3.0.1, DS18B20.1, H1.B3,0, H2.B3,0, H3.B3,0, H4.B3,0, J4.10
RST: J3.11
VBAT: BATTERIES.2, BOOSTER.3
VCC: BOOSTER.1, D0-METER-V3.0.2, DS18B20.3, J4.11, R1.1

Board: 2 copper layers, 11 parts (0 on the bottom side), 5 nets, no tracks yet.

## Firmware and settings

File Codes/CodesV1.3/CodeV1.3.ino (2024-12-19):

// ====================================================================================================
// Nom du projet: Dispositif de mesure de la qualité de l'eau d'un lac ou d'une rivière avec géolocalisation connecté à internet (Cloud)
// Date: Vendredi 20 novembre 2024
// Auteur(s): Membres de L'epuipe CAKE
// Description: Code .ino pour le Dispositif de mesure de la qualité de l'eau d'un lac ou d'une rivière avec géolocalisation connecté à internet (Cloud)
// Version: v1.20
// ====================================================================================================

#include <lmic.h>
#include <hal/hal.h>
#include <SPI.h>
#include <OneWire.h>
#include <DallasTemperature.h>
#include "ATcommands.h"
#include "wiring_private.h"
#include <TinyGPSPlus.h>

// D2-TX, D3-RX
Uart mySerial(&sercom2, 3, 2, SERCOM_RX_PAD_1, UART_TX_PAD_2);
TinyGPSPlus gps;                            // Crée un objet TinyGPSPlus pour gérer la localisation GPS

void SERCOM2_Handler() {
    mySerial.IrqHandler();
}

#define CapteurO2 A0
#define ONE_WIRE_BUS 4

OneWire oneWire(ONE_WIRE_BUS);              // Objet pour la communication 1-Wire
DallasTemperature sensors(&oneWire);        // Passe l'objet à la bibliothèque DallasTemperature pour la gestion des capteurs de température

// Pins utilisés pour contrôler le module RA-07H
int PWR_KEY = 9;                            // Pin pour activer/désactiver l'alimentation du module
int RST_KEY = 6;                            // Pin pour réinitialiser le module
int LOW_PWR_KEY = 5;                        // Pin pour activer/désactiver le mode basse consommation du module

// Variables pour gérer les envois et gérer les erreurs potentielles
int retryCount = 0;                         // Compteur de tentatives d'envoi de données
const int maxRetries = 3;                   // Nombre maximum de tentatives pour l'envoi de paquets LoRaWAN
bool ackReceived = false;                   // Indicateur pour savoir si un accusé de réception (ACK) a été reçu

// Identifiants LoRaWAN à remplacer par ceux de votre réseau
String deveui = "xxx";                      // DEVEUI unique de l'appareil
String appeui = "yyy";                      // APPEUI de l'application
String appkey = "zzz";                      // APPKEY pour l'authentification

// Compteur pour l'envoi des données LoRaWAN
int counter = 0;                            // Compteur qui sera envoyé périodiquement via LoRaWAN

void setup() {
    pin_init();                             // Initialisation des broches du module
    SerialUSB.begin(115200);                // Initialisation de la communication série avec le PC pour débogage
    Serial1.begin(115200);                  // Initialisation de la communication avec le module RA-07H

    delay(1000);
    SerialUSB.println("Initialisation du terminal LoRaWAN avec RA-07H...");

    configureModule();                      // Configure le module LoRaWAN avec les paramètres nécessaires

    joinNetwork();                          // Tente de rejoindre le réseau LoRaWAN

    mySerial.begin(9600);                   // Démarre la communication série pour le GPS

    // Configure les pins SERCOM pour la communication GPS sur RX et TX
    pinPeripheral(2, PIO_SERCOM);
    pinPeripheral(3, PIO_SERCOM_ALT);
}

void loop() {
    // Lire les données des capteurs
    int iValeurCapteur = analogRead(CapteurO2); 
    float fTension = iValeurCapteur * (3.3 / 1023.0);
    float do_mg_per_l = fTension * 20;      // Conversion en mg/L

    sensors.requestTemperatures();
    float temperatureC = sensors.getTempCByIndex(0);
        
    // Convertir en entiers
    int O2 = (int)do_mg_per_l;              // Oxygène en mg/L (valeur entière)

    // Lire les données du GPS
    while (mySerial.available() > 0) {
        gps.encode(mySerial.read());
        
        // Vérifie si une nouvelle mise à jour de la position GPS est disponible
        if (gps.location.isUpdated()) {
            SerialUSB.print("Latitude: ");
            SerialUSB.println(gps.location.lat());
            SerialUSB.print("Longitude: ");
            SerialUSB.println(gps.location.lng());
            SerialUSB.print("Altitude: ");
            SerialUSB.print(gps.altitude.meters());
        }
    }

    // Si un accusé de réception est reçu ou si nous n'avons pas atteint le maximum de tentatives
    if (ackReceived || retryCount < maxRetries) {
        sendData(temperatureC, O2);         // Envoie la valeur actuelle du compteur et des données capteurs
        counter++;                          // Incrémentation du compteur à chaque envoi réussi ou tenté
    } else {
        SerialUSB.println("Nombre maximum de tentatives atteint, abandon de l'envoi.");
    }

    delay(5000);                            // Attendre 5 secondes avant d'envoyer de nouvelles données
}

// ====================================================================================================
// Bloc de la fonction pour configurer le module RA-07H avec les paramètres requis pour la connexion LoRaWAN
// - Cette fonction désactive l'ADR, ajuste la puissance de transmission et configure les identifiants OTAA.
// ====================================================================================================
void configureModule() {
    SerialUSB.println("Configuration du module RA-07H...");

    sendATCommand("AT+CRESTORE");
    sendATCommand("AT+CADR=1");             // Activer l'ADR (Adaptive Data Rate)
    sendATCommand("AT+CFREQBANDMASK=0002"); // Configurer un débit de données élevé (DR3)
    sendATCommand("AT+CTXP=5");             // Configurer la puissance de transmission à 5 dBm

    // Configurer les identifiants OTAA (DEVEUI, APPEUI, APPKEY)
    sendATCommand("AT+CDEVEUI=" + deveui);  // Configurer le DEVEUI unique de l'appareil
    sendATCommand("AT+CAPPEUI=" + appeui);  // Configurer l'APPEUI de l'application
    sendATCommand("AT+CAPPKEY=" + appkey);  // Configurer l'APPKEY pour l'authentification

    sendATCommand("AT+CSAVE");              // Sauvegarder la configuration dans le module pour éviter de répéter la configuration à chaque redémarrage

    SerialUSB.println("Configuration terminée.");
}

// ====================================================================================================
// Bloc de la fonction pour rejoindre le réseau LoRaWAN en utilisant OTAA (Over The Air Activation)
// - Une attente de 15 secondes est nécessaire pour laisser le temps au module de se connecter.
// ====================================================================================================
void joinNetwork() {
    SerialUSB.println("Tentative d'adhésion au réseau LoRaWAN...");
    sendATCommand("AT+CJOIN=1,0,10,8");     // Rejoindre le réseau avec OTAA (essayer pendant 10 secondes)
    delay(15000);                           // Attendre 15 secondes pour la jonction
}

// ====================================================================================================
// Bloc de la fonction pour envoyer des données via le réseau LoRaWAN
// - L'envoi est effectué avec un payload comprenant la valeur actuelle du compteur
// ====================================================================================================
void sendData(float temp, int O2Value) {
    // Convertir la température en entier (en supprimant la partie décimale)
    int tempInt = (int)temp;

    // Convertir la température en hexadécimal sous forme de chaîne
    char hexString[5];
    sprintf(hexString, "%04X", tempInt);

    char hexString2[5];
    sprintf(hexString2, "%04X", O2Value);

    // Vérifiez la position GPS et préparez les données pour Latitude, Longitude et Altitude
    float latitude = gps.location.lat();
    float longitude = gps.location.lng();
    float altitude = gps.altitude.meters();
    
    // Convertir latitude, longitude et altitude en entiers
    long latInt = (long)(latitude * 1000000.0);   // Multiplier par 1 000 000 pour avoir une précision à 6 décimales
    long longInt = (long)(longitude * 1000000.0); // Multiplier par 1 000 000 pour avoir une précision à 6 décimales
    int altInt = (int)altitude;                   // Altitude est généralement en mètres

    // Convertir en hexadécimal
    char latHexString[9];                   // 8 caractères hexadécimaux + 1 pour le caractère nul
    char longHexString[9];                  // 8 caractères hexadécimaux + 1 pour le caractère nul
    char altHexString[5];                   // 4 caractères hexadécimaux + 1 pour le caractère nul
    
    sprintf(latHexString, "%08X", latInt);
    sprintf(longHexString, "%08X", longInt);
    sprintf(altHexString, "%04X", altInt);
    
    String payload = String(hexString);
    String payload2 = String(hexString2);
    String payload3 = String(latHexString);
    String payload4 = String(longHexString);
    String payload5 = String(altHexString);

    // Préparer et envoyer la température
    String commandTemp = "AT+DTRX=1,2," + String(payload.length()) + ",01" + payload;
    sendATCommand(commandTemp);
    delay(1000);
    
    SerialUSB.print("Envoi de données Temp : " + payload + "  / ");
    SerialUSB.println(tempInt);
    
    // Envoyer la valeur d'O2
    String commandO2 = "AT+DTRX=1,2," + String(payload2.length()) + ",02" + payload2;
    sendATCommand(commandO2);
    SerialUSB.print("Envoi de données O2 : " + payload2 + "  / ");
    SerialUSB.println(O2Value);

    //Envoyer latitude
    String commandLat = "AT+DTRX=1,2," + String(payload3.length()) + ",03" + payload3;
    sendATCommand(commandLat);
    SerialUSB.print("Envoi de Latitude : " + payload3 + "  / ");
    SerialUSB.println(latInt);

    // Envoyer longitude
    String commandLong = "AT+DTRX=1,2," + String(payload4.length()) + ",04" + payload4;
    sendATCommand(commandLong);
    SerialUSB.print("Envoi de Longitude : " + payload4 + "  / ");
    SerialUSB.println(longInt);

    // Envoyer altitude
    String commandAlt = "AT+DTRX=1,2," + String(payload5.length()) + ",05" + payload5;
    sendATCommand(commandAlt);
    SerialUSB.print("Envoi d'Altitude : " + payload5 + "  / ");
    SerialUSB.println(altInt);
}

// ====================================================================================================
// Bloc de la fonction pour envoyer une commande AT au module RA-07H et lire la réponse
// - Cette fonction envoie une commande AT et imprime la réponse du module sur le terminal de débogage
// ====================================================================================================
void sendATCommand(String command) {
    Serial1.println(command);               // Envoie la commande AT au module RA-07H
    delay(1500);                            // Attendre une réponse du module

    // Lire et imprimer la réponse du module
    while (Serial1.available()) {
        String response = Serial1.readStringUntil('\n');
        SerialUSB.println(response);        // Afficher la réponse sur le terminal
    }
}

// ====================================================================================================
// Bloc de la fonction pour initialiser les pins du module RA-07H
// - Cette initialisation est nécessaire pour contrôler correctement le module et le mettre sous tension.
// ====================================================================================================
void pin_init() {
    pinMode(PWR_KEY, OUTPUT);               // Configurer la broche PWR_KEY comme sortie
    pinMode(RST_KEY, OUTPUT);               // Configurer la broche RST_KEY comme sortie
    pinMode(LOW_PWR_KEY, OUTPUT);           // Configurer la broche LOW_PWR_KEY comme sortie

    // Séquence d'initialisation pour mettre sous tension et réinitialiser le module
    digitalWrite(RST_KEY, LOW);             // Maintenir le module en état réinitialisé
    digitalWrite(LOW_PWR_KEY, HIGH);        // Désactiver le mode basse consommation
    digitalWrite(PWR_KEY, HIGH);            // Alimenter le module

    digitalWrite(PWR_KEY, LOW);             // Cycle de mise sous tension
    delay(3000);
    digitalWrite(PWR_KEY, HIGH);
    delay(10000);                           // Attendre que le module soit complètement initialisé
}

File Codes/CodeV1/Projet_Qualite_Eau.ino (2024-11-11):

#include <lmic.h>
#include <hal/hal.h>
#include <SPI.h>
#include <OneWire.h>
#include <DallasTemperature.h>

#define CapteurO2 A0
#define ONE_WIRE_BUS 4

OneWire oneWire(ONE_WIRE_BUS); // objet pour communication 1 wire 
DallasTemperature sensors(&oneWire); // passer l'objet à DallasTemperature

// Pin mapping -- set your pin numbers here. These are for the Dragino shield.
const lmic_pinmap lmic_pins = {
    .nss = 10, 
    .rxtx = LMIC_UNUSED_PIN, 
    .rst = 9, 
    .dio = {2, 6, 7},
};

// Insert Device EUI here
static const u1_t PROGMEM DEVEUI[8] = { XXX };
void os_getDevEui (u1_t* buf) { memcpy_P(buf, DEVEUI, 8);}

// Insert Application EUI here
static const u1_t PROGMEM APPEUI[8] = { YYY };
void os_getArtEui (u1_t* buf) { memcpy_P(buf, APPEUI, 8);}

// Insert App Key here
static const u1_t PROGMEM APPKEY[16] = { ZZZ ;
void os_getDevKey (u1_t* buf) { memcpy_P(buf, APPKEY, 16);}

// Schedule uplink to send every TX_INTERVAL seconds
const unsigned TX_INTERVAL = 30;

void do_send(osjob_t* j) {
    if (LMIC.opmode & OP_TXRXPEND) {
        SerialUSB.println(F("OP_TXRXPEND, not sending"));
    } else {
        // Lire les données des capteurs
        int iValeurCapteur = analogRead(CapteurO2); 
        float fTension = iValeurCapteur * (3.3 / 1023.0);
        float do_mg_per_l = fTension * 20; // Conversion en mg/L

        sensors.requestTemperatures();
        float temperatureC = sensors.getTempCByIndex(0);
        
        // Convertir en entiers
        int doInt = (int)do_mg_per_l; // Oxygène en mg/L (valeur entière)

        // Préparer le payload (en supposant qu'on envoie 2 valeurs)
        byte payload[4]; // 2 octets pour la température et 2 pour l'oxygène
        payload[0] = (byte)temperatureC; // température en entier
        payload[1] = (byte)((temperatureC - (int)temperatureC) * 100); // partie décimale
        payload[2] = lowByte(doInt); // oxygène en mg/L
        payload[3] = highByte(doInt); 

        // Envoyer le paquet
       LMIC_setTxData2(1, payload, sizeof(payload), 0);
        SerialUSB.println(F("Payload queued"));
    }
}

static osjob_t sendjob;
void onEvent(ev_t ev) {
    switch(ev) {
        case EV_JOINING:
            SerialUSB.println("EV_JOINING");
            break;
        case EV_JOINED:
            SerialUSB.println("EV_JOINED");
            LMIC_setLinkCheckMode(0);
            break;
        case EV_JOIN_FAILED:
            SerialUSB.println("EV_JOIN_FAILED");
            break;
        case EV_REJOIN_FAILED:
            SerialUSB.println("EV_REJOIN_FAILED");
            break;
        case EV_TXCOMPLETE:
            SerialUSB.println("EV_TXCOMPLETE");
            os_setTimedCallback(&sendjob, os_getTime() + sec2osticks(TX_INTERVAL), do_send);
            break;
        default:
            break;
    }
}

void setup() {
    SerialUSB.begin(9600);
    SerialUSB.println(F("Starting"));
    os_init();
    LMIC_reset();
    LMIC_setLinkCheckMode(0);
    LMIC_setDrTxpow(DR_SF7, 14);
    
    sensors.begin(); // Initialiser le capteur de température
    do_send(&sendjob); // Envoyer les données pour la première fois
}

void loop() {
    os_runloop_once();
    SerialUSB.println(F("Started"));
}

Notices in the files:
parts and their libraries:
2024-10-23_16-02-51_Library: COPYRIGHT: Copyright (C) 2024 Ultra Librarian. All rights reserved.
